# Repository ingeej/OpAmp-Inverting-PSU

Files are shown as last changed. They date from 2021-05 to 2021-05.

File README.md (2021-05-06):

# OpAmp-Inverting-PSU
Cheap breadboard friendly PCB to provide regulated +-5V from a micro USB.

The project is created in colaboration with NTNU, for use in a introduction course to electronics. 

It utilizes a TI LM2775 to first regulate the USB input voltage to a regulated 5V and then a LM2776 to invert the voltage to -5V. 
The ICs are rated for 200mA and have built in short circuit protection.

All parts are sorted from JLC PCB in order to keep production assembly cost at a minimum.

Know faults: 
Inverter does not work if -5V is pulled high by a resistor. This can be fixed with a FV diode.

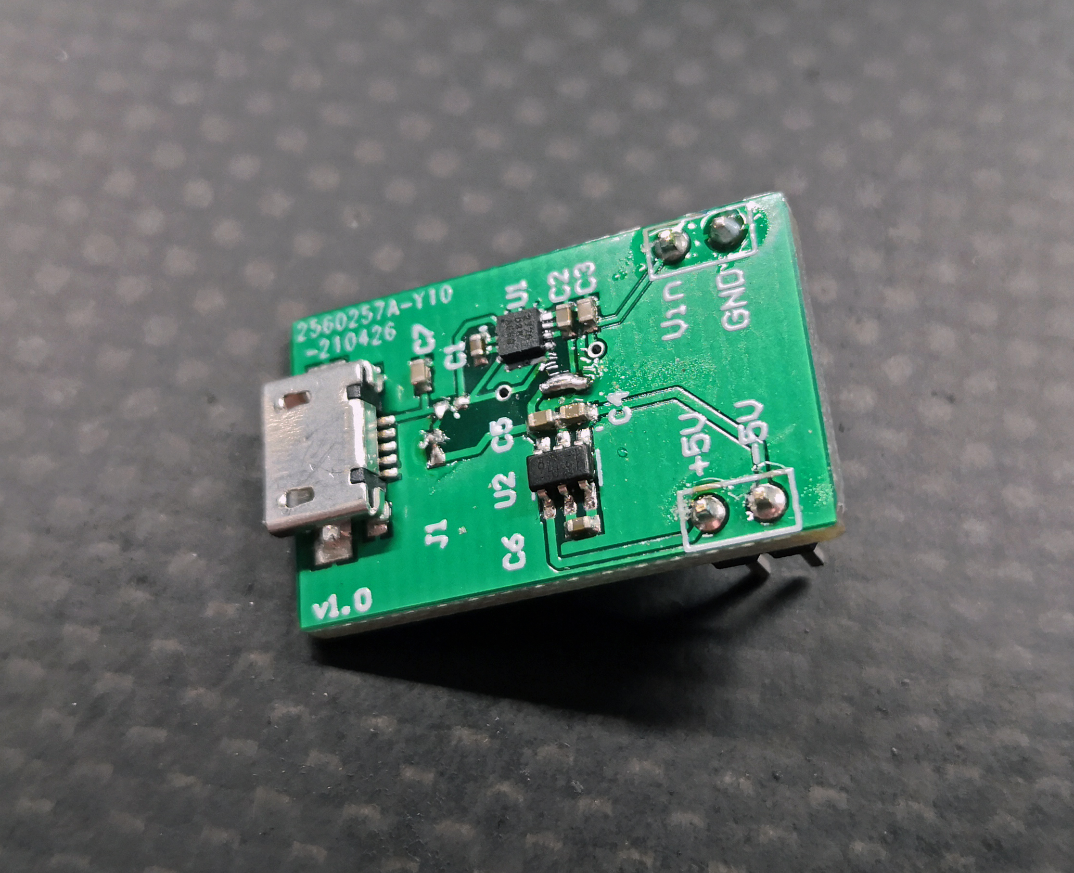
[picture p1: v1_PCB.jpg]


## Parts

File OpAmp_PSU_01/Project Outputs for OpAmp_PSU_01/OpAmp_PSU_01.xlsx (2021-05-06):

Comment | Description | Designator | Footprint | LibRef | Quantity
1uF 0402 Cap | C52923 | C1, C6 | 0402 Cap | 1uF 0402 Cap | 2 | 50
10uF 0402 Cap | C15525 | C2, C3, C4, C5, C7 | 0402 Cap | 10uF 0402 Cap | 5 | 50
USB Connectors SMD RoHS Source: Datasheet | C40942 | J1 | C40942 | C40942 | 1
2 1 pin straight | C390678 | J1, J2 | 2 1 pin staright | 2 1 pin straight | 2
LM2775DSGR | C473361 | U1 | SON50P200X200X80-9N | LM2775DSGR | 1
LM2776DBVR | C69527 | U2 | SOT95P280X145-6N | LM2776DBVR | 1

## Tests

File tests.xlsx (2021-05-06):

Data: | 05.05.2021
NOTE: | V+ is overall slightly high by 0.1V. V- is low by 0.05V. Does not work if load pulls V- high, ie a resitor. When short circuited, lm2775 gets very hot, but works fine afterwards (5min short cicuit) - pulls aprox 250-300mah when SC.
test with LM2775 detached from rest of circuit, no load |  |  |  | test of entire circuit with 140ohm+led as load. Connected to psu, not usb |  |  |  | Usb attached, same 130ohm led load, pulls 140mAh
 | VIN | VOUT | VOUT #2
 | 4.488 | 5.092 | 5.029 | PSU | VOUT+ | VOUT- |  | USB VOUT | V+ | V-
 | 3.976 | 5.088 |  | I = 140mAh @ 5V | 5.039 | -4.952 | Board #1 | 5.025 | 5.023 | -4.939
 | 5.479 | 5.109 |  | I =143 @ 4.5V | 5.025 | -4.937 | Board #1 | 5.068 | 5.065 | -4.981
 | 5.18 | 5.104 |  | I = 138 @ 5.30V | 5.055 | -4.967 | Board #2 | 4.999 | 4.997 | -4.911
 | 3.285 | 5.083 |  |  |  |  | Board #2 | 5.071 | 5.069 | -4.984
